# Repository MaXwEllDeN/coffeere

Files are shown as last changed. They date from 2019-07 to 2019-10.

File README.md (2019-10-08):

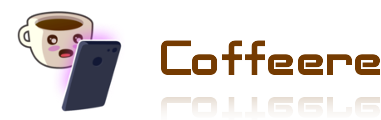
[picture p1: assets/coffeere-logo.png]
alt logo

# Coffeere


## Overview

Coffeere is a platform for those of you who got tired of going to the kitchen just to realize that the coffee bottle is empty :tired_face:.

## Requirements

* [HX711 Weight Load library](https://github.com/bogde/HX711)
* [ESP8266 FS Tool](https://github.com/esp8266/arduino-esp8266fs-plugin)
* [ArduinoJson library version 6.12.0](https://github.com/bblanchon/ArduinoJson)

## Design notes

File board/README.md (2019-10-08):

alt logo
# Coffeere


## Board

This directory contains the [Autodesk's EAGLE](https://www.autodesk.com/products/eagle/overview) project files needed to produce the board.

## Printed Circuit Board

### Board after the layout transference
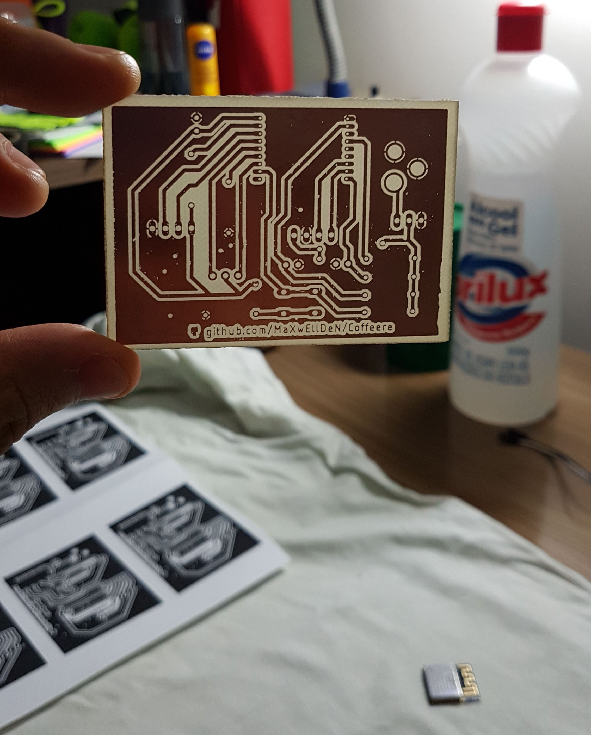
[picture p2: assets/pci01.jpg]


### Board with ESP8266-12e soldered
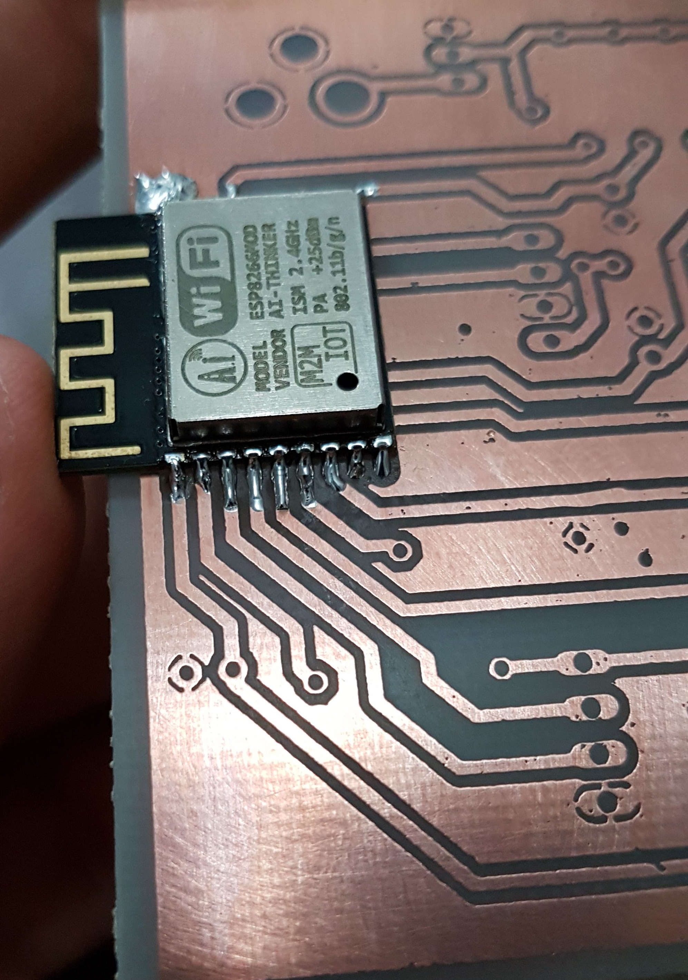
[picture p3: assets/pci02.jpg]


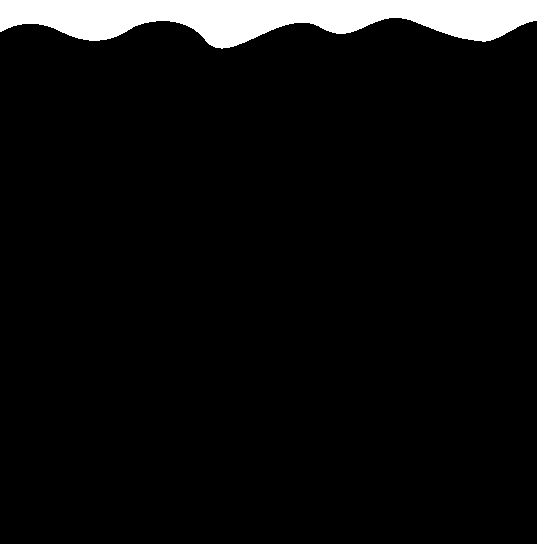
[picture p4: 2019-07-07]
src/client/waves.png

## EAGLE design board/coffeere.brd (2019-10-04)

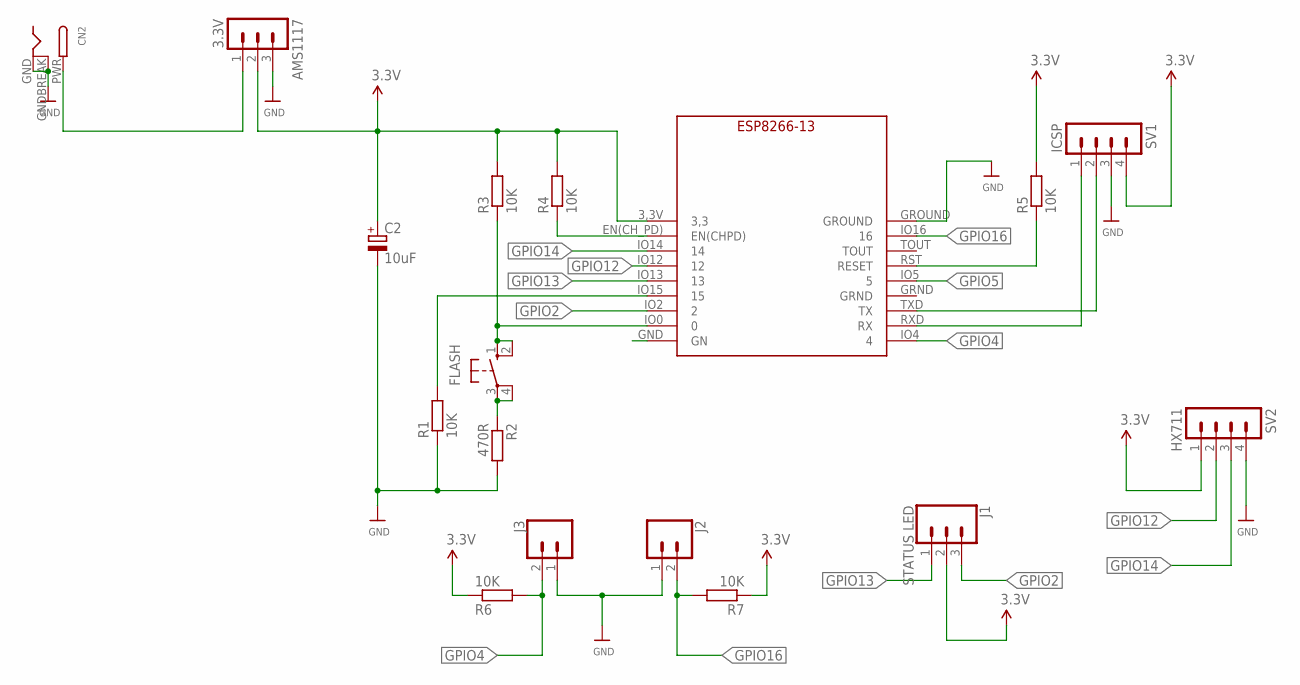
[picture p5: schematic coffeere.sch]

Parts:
AMS1117: 3.3V; MA03-1
C2: 10uF; E2,5-6
CN2: DCBARRELPTH; DCJACK_2MM_PTH
FLASH: 10-XX; B3F-10XX
J1: STATUS LED; 1X03
J2, J3: CONN_02; 1X02
R1, R3, R4, R5, R6, R7: 10K; 0207/10
R2: 470R; 0207/10
SV1: ICSP; MA04-1
SV2: HX711; MA04-1
U$1: ESP8266-13

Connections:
3.3V: AMS1117.2, C2.+, J1.2, R3.2, R4.2, R5.2, R6.1, R7.1, SV1.4, SV2.1, U$1.3,3V (3,3)
GND: AMS1117.3, C2.-, CN2.GND, CN2.GNDBREAK, J2.1, J3.1, R1.1, R2.2, SV1.3, SV2.4, U$1.GROUND
GPIO0: FLASH.1 (S), FLASH.2 (S1), R3.1, U$1.IO0 (0)
GPIO2: J1.3, U$1.IO2 (2)
GPIO4: J3.2, R6.2, U$1.IO4 (4)
GPIO5: U$1.IO5 (5)
GPIO12: SV2.2, U$1.IO12 (12)
GPIO13: J1.1, U$1.IO13 (13)
GPIO14: SV2.3, U$1.IO14 (14)
GPIO15: R1.2, U$1.IO15 (15)
GPIO16: J2.2, R7.2, U$1.IO16 (16)
unnamed: AMS1117.1, CN2.PWR
unnamed: SV1.2, U$1.TXD (TX)
unnamed: SV1.1, U$1.RXD (RX)
unnamed: FLASH.3, FLASH.4 (P1), R2.1
unnamed: R5.1, U$1.RST (RESET)
unnamed: R4.1, U$1.EN(CH_PD) (EN(CHPD))

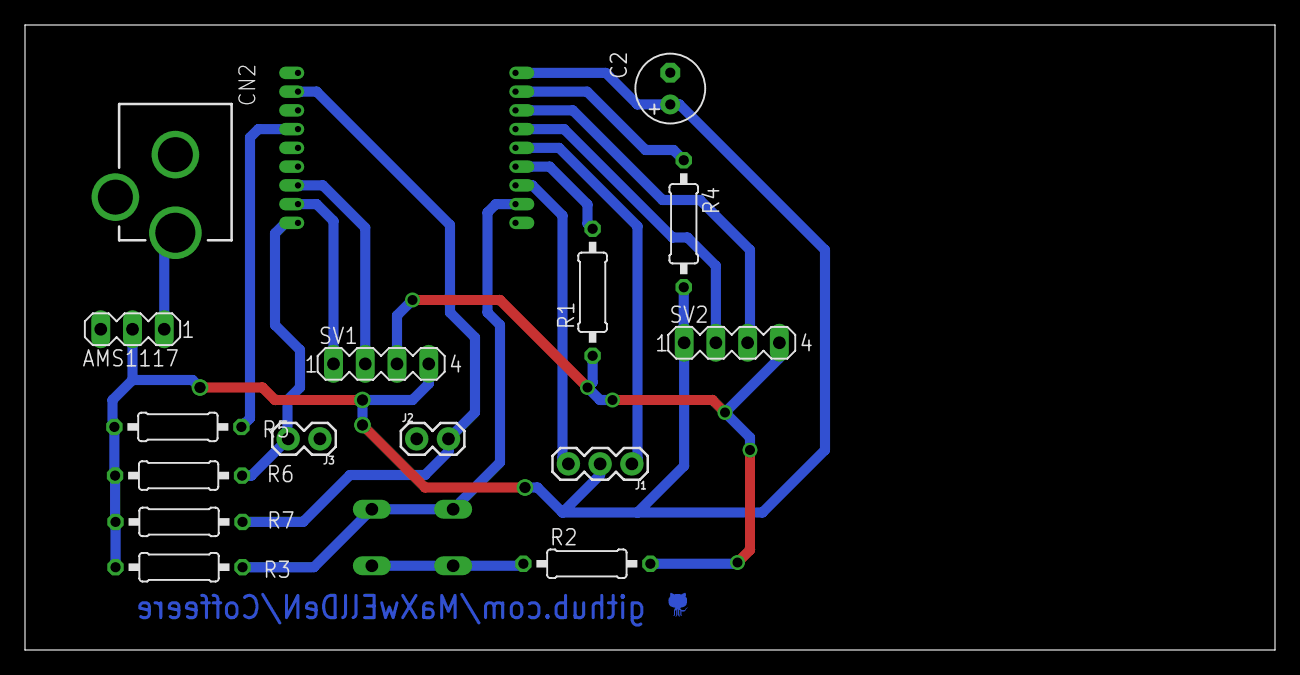
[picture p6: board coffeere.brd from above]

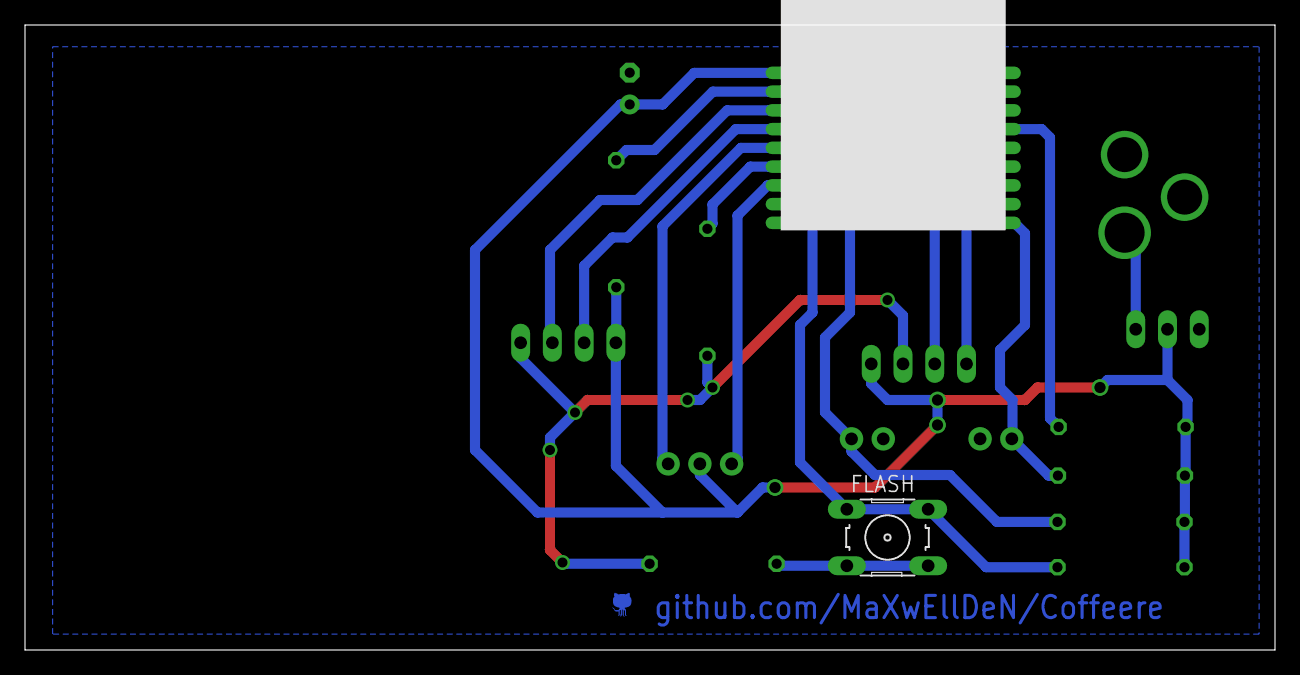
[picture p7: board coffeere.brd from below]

Board: 2 copper layers, 100.0 x 50.0 mm, 17 parts (2 on the bottom side), 16 nets.

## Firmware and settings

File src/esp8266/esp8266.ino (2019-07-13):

#include "FS.h"
#include "const.h"
#include "webserver.h"
#include "functions.h"
#include "HX711.h"

#define DEBUG 1
MODULE_MODE operation_mode;

Webserver server;
HX711 scale;

int counterToPost = 0;
int counterWifiTimeout = 0;
int counterToReset = 0;

void startConfigurationMode()
{
  WiFi.mode(WIFI_AP_STA);

  IPAddress ap_ip(18, 13, 0, APPLET_IP_IDENTIFIER);
  WiFi.softAPConfig(ap_ip, IPAddress(18, 13, 0, 0), IPAddress(255, 255, 255, 0));
  WiFi.softAP(AP_SSID);

  server.begin();
}

void setup() {
  pinMode(PIN_LED_RED, OUTPUT);
  pinMode(PIN_LED_GREEN, OUTPUT);

  pinMode(PIN_BUTTON_TARE, INPUT_PULLUP);
  pinMode(PIN_BUTTON_RESET, INPUT_PULLUP);

  setLedStatus(LED_STATUS_RED);

  Serial.begin(115200);
  delay(10);
  Serial.println("Iniciando Coffere");
  SPIFFS.begin();

  if (!isAppletConfigured()) {
    operation_mode = CONFIGURATION_MODE;
    startConfigurationMode();
    Serial.println("Entrando em modo de configuração.");
  }
  else {
    Serial.println("Entrando em modo de funcionamento normal.");
    Serial.print("SSID Salvo:`");
    Serial.print(getSavedSSID());
    Serial.println("`");

    scale.begin(PIN_HX711_DOUT, PIN_HX711_CLK);
    WiFi.mode(WIFI_OFF);        //Prevents reconnection issue (taking too long to connect)
    delay(1000);

    scale.set_scale(SCALE_CALIBRATION_FACTOR);
    scale.set_offset(getSavedOffset());

    Serial.print("Saved ScaleOffset: ");
    Serial.println(getSavedOffset());

    WiFi.mode(WIFI_STA);
    WiFi.begin(getSavedSSID().c_str(), getSavedPassword().c_str());

    #ifdef __DEBUG__
    Serial.println("");
    Serial.print("Connecting");
    #endif // __DEBUG__

    // Wait for connection
    while (WiFi.status() != WL_CONNECTED) {
      if (counterWifiTimeout >= TIMEOUT_WIFI_CONNECT) {
        setLedStatus(LED_STATUS_RED);
        break;
      }

      setLedStatus(LED_STATUS_OFF);
      counterWifiTimeout += 500;
      delay(250);
      setLedStatus(LED_STATUS_RED);
      delay(250);

      #ifdef __DEBUG__
      Serial.print(".");
      #endif // __DEBUG__
    }

    if (WiFi.status() != WL_CONNECTED) {
      operation_mode = CONFIGURATION_MODE;
      startConfigurationMode();
    }
    else {
      operation_mode = WORKING_MODE;
      setLedStatus(LED_STATUS_GREEN);

      #ifdef __DEBUG__
      Serial.println("");
      Serial.print("Connected to ");
      Serial.println(ssid);
      Serial.print("IP address: ");
      Serial.println(WiFi.localIP());
      #endif // __DEBUG__      
    }
  }
}

void loop() {
  if (operation_mode == CONFIGURATION_MODE) {
    server.getServerObject()->handleClient();
  }
  else if (operation_mode == WORKING_MODE) {

    if (!digitalRead(PIN_BUTTON_TARE)) {
      setLedStatus(LED_STATUS_RED);

      double sum = scale.read_average();
      scale.set_offset(sum);
      saveScaleOffset(sum);
      delay(500);

      counterToPost += 500;
    }
    
    while(!digitalRead(PIN_BUTTON_RESET)) {
      setLedStatus(LED_STATUS_YELLOW);

      if (counterToReset >= TIME_PRESSING_TO_RESET) {
        setLedStatus(LED_STATUS_RED);
        resetConfiguration();       
        restartApplet();
        break;
      }

      counterToReset += 100;
      counterToPost += 100;

      delay(100);
    }

    counterToReset = 0;

    if (counterToPost >= 2000) {
      int httpCode = postWeight(scale);
      counterToPost = 0;

      if (httpCode == 200) {
        setLedStatus(LED_STATUS_GREEN);
      }
      else {
        setLedStatus(LED_STATUS_RED);
      }
    }

    counterToPost += 100;
    delay(100);
  }
}

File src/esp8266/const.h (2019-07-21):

#ifndef _H_CONSTANT
#define _H_CONSTANT

#define APPLET_IP_IDENTIFIER          1
#define TIMEOUT_WIFI_CONNECT          60000
#define TIME_PRESSING_TO_RESET        4
#define SCALE_CALIBRATION_FACTOR      300

#define PIN_HX711_DOUT      14
#define PIN_HX711_CLK       12

#define PIN_LED_RED         13
#define PIN_LED_GREEN       2
#define PIN_BUTTON_RESET    4
#define PIN_BUTTON_TARE     16

enum MODULE_MODE {
  CONFIGURATION_MODE,
  WORKING_MODE
};

enum LED_STATUS {
  LED_STATUS_OFF,
  LED_STATUS_RED,
  LED_STATUS_GREEN,
  LED_STATUS_YELLOW
};

static const char *HOST_ENDPOINT = "http://maxwellden.pythonanywhere.com/weight";
static const char *AP_SSID = "Coffeere";

#endif // _H_CONSTANT

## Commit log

2019-07-12 Fixing isAppletConfigured issue.
    [schematic.sch]
2019-07-12 Adding clausure to ignore Eagle's schematic backup files.
2019-07-13 Updating button handler.
2019-07-21 Changing pinout to better suit the board design.
2019-07-21 Creating schemetic and board designs.
    [coffeere.brd, coffeere.sch]
2019-07-21 Renaming coffere.ino -> esp8266.ino due to Arduino requirement.
2019-10-04 Fixing board issues
    [coffeere.brd]
2019-10-08 Update README.md
    Adding ArduinoJson library as requirement.
2019-10-08 Updating board's directory README.md.

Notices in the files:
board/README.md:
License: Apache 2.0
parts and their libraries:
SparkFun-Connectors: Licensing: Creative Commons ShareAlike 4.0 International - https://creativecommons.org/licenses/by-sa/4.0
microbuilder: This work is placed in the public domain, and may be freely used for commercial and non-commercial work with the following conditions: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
